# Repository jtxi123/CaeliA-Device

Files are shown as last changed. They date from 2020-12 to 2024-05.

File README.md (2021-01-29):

# CaeliA-Device

## Device using MHZ19 and DHT11 sensors

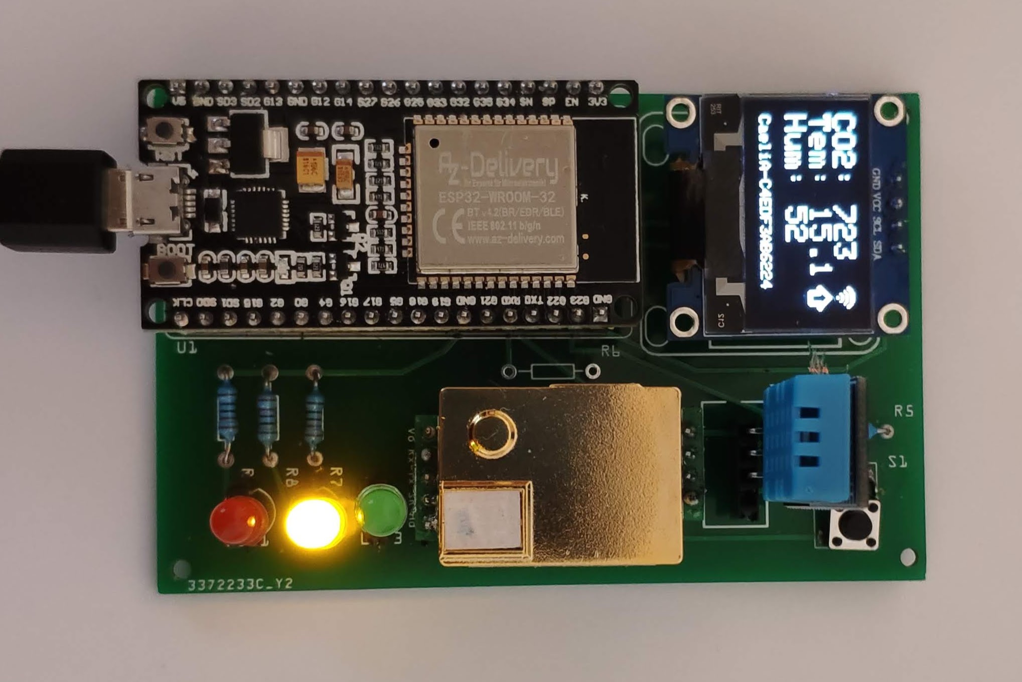
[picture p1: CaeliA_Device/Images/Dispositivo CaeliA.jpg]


## Device using CM1106 and BME280 sensors

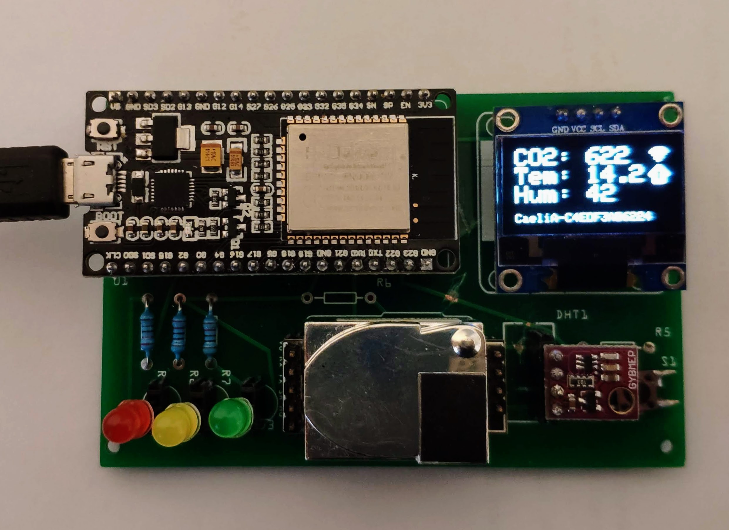
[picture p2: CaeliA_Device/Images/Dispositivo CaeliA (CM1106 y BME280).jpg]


This project describes the design of a CO2 metering for deployment in schools and other public and private places.

The device takes CO2 as well as other environmental readings periodically and publishes them using mqtt to a cloud platform.
The device is equiped with a display and some indicator leds in order to also allow local operation and to signal the warning
CO2 levels.

The device was built using an ESP32 nodemcu and utilizes two sensors:
* MHZ19 or CM1106 CO2 sensor: 
    - An NDIR co2 sensor that supports a serial UART interface.
* DHT11 or BME280 Humidity and Temperature sensor: 
    - The sensor provides temperature and humidity and is interfaced though a PWM
* The software is designed to automatically detect which sensor is present and will use the corresponding sensor for CO2, temperature and humidity.

The device needs a wifi hotspot to connect to Internet and publish the readings.

In order to connect, the device uses the [WifiManager library](https://github.com/tzapu/WiFiManager) to request from the user the connection parameters. 

* On first instalation, the device will start a captive portal AP and request the following:
    - WiFi SSID
    - WiFi password
    - MQTT broker address
    - MQTT broker port
    - MQTT topic
    - URL to check for software updates.
* After parameters are set, the device will connect automatically without user intervention. Parameters are persisted
in the flash SPFFS file system and will be recovered in subsequent reboots.
* The user can force the device to raise the captive portal upon powerup to change any of the existing parameters.

# Calibration

NDIR CO2 sensors must be periodically calibrated to compensate drifts. The device supports three methods:

* Autocalibration (on by default): Whe operating under normal conditions, in operation the device assumes that at some point during a 24h period there will be a base level concentratio (approx. 400ppm) and uses that point to calibrate. 

* Manual calibration: Pressing the multipurpose button while the device is on operation in a base level CO2 concentration will force the device to follow a calibration cycle

* Sending a command from the server (see RPC commands).

The device uses the [fota library](https://github.com/chrisjoyce911/esp32FOTA) library for over the air updates. In will regularly check for firmware updates by checking current firmware version against the version recorded in the sw server.
In the case there is a new version it will download and install it unattended.

# Configuration

When the device stars up it recovers the configuration stored in flash memory and tries to connect. If it succeds i proceeds with the setup and follows to start taking readings from the sensor and publishing them via mqtt. The reading cycle takes place every 20s although it is easy to change.

Onece selected the AP of the arduino board the following screens allo you to configure the different parameters:

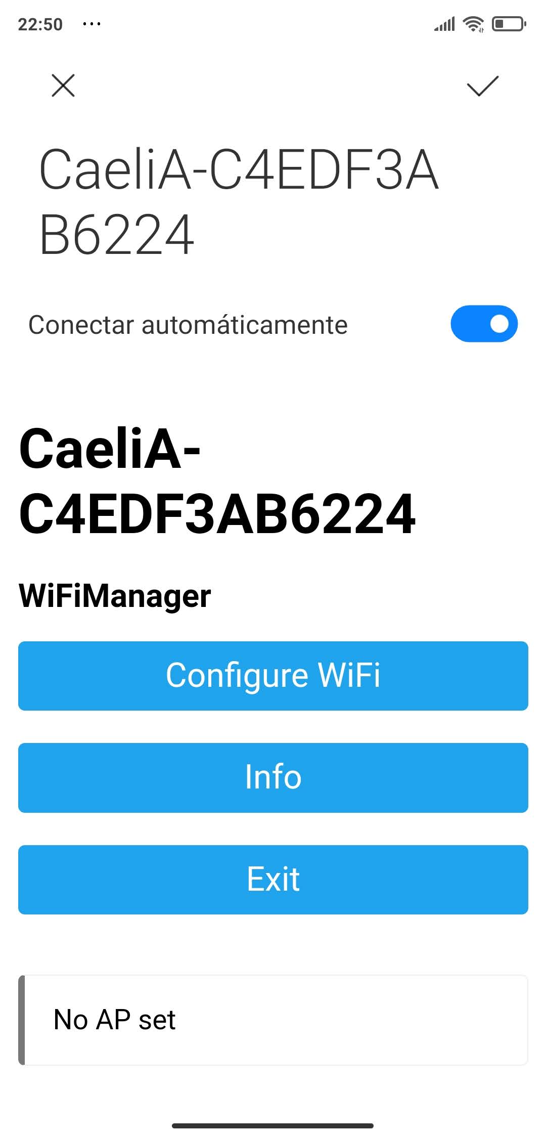
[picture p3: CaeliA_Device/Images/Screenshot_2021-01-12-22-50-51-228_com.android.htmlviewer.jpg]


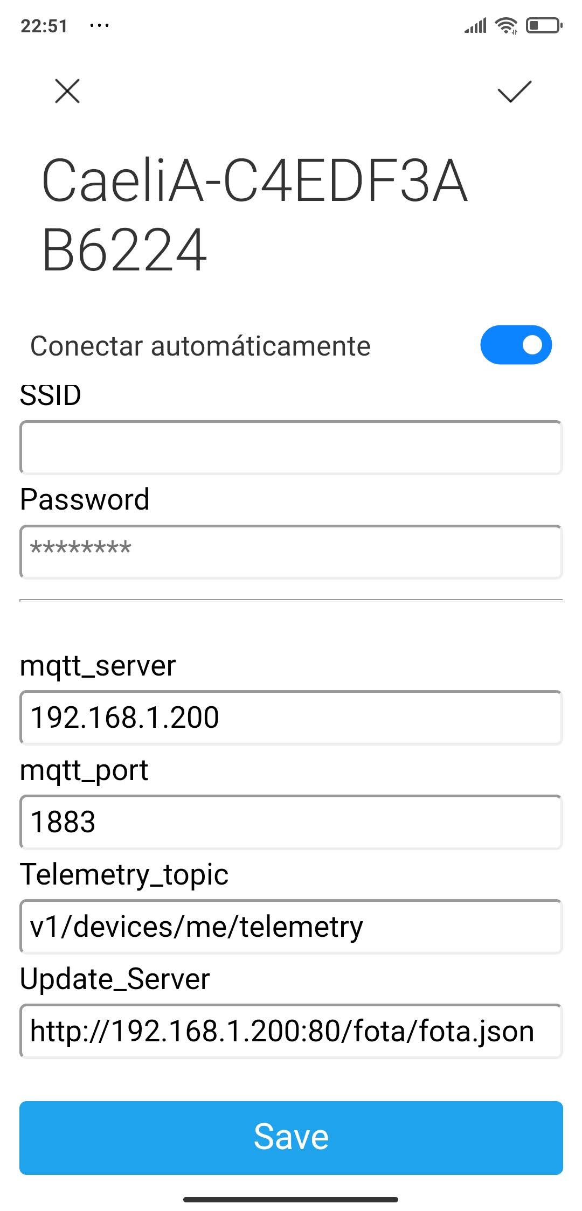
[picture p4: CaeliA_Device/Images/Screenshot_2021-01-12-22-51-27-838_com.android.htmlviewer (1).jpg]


# OTA software update

The device checks periodically a json file stored in a web server, to verify if there is a newer version than the current software loaded on the device. The file also points to the location of the sw which can be stored in a different server. 

```
{
    "type": "CaeliA_esp32_co2",
    "version": 1,
    "host": "192.168.1.200",
    "port": 80, 
    "bin": "/fota/CaeliA_Device.ino.esp32.bin"
}
```

# MQTT Cloud platform

CaeliA device is conceived as a device used to publish into a cloud platform. The cloud platform can also be used to manage the device.

Data on the device can be visualized thoug dashboards such as:

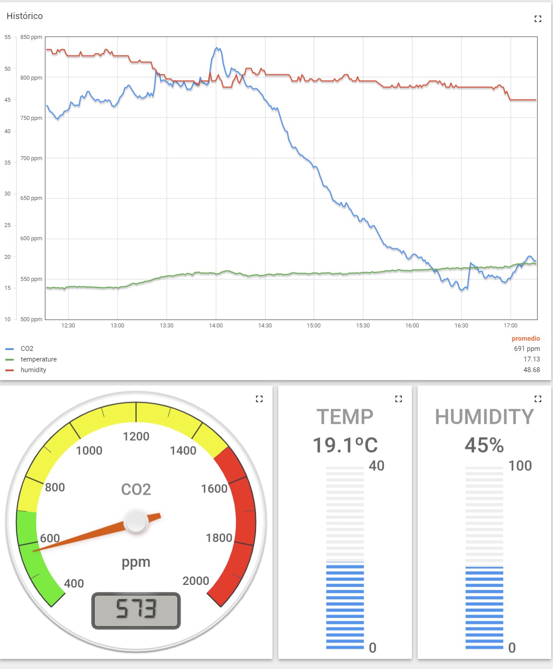
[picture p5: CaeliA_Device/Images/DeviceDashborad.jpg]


The current platform used is ThingsBoard which allows also also to issue RPC commands that the device can interpret. Curtrently the following
RPC calls over MQTT are implemented:

```
setOffset: Add offset to CO2 reading#define DBG_ENABLE_ERROR
calibration: Zero calibration of  device (400 ppm)
autoCalibration: turn autocalibration  on/off
userMessage: Display a message for the user
setLedState: Force LEDs on(2)/off(0)/warning_level(1)
setWarnings: Define warning and danger levels
autoCalibration: turn the autocalibration mode on=true or off=false
version: the device will respond with the uptime and the version number
updateFirmware: the device will load new firmware from the host and filedescriptor parameters
```
 
# Schematics of the device:

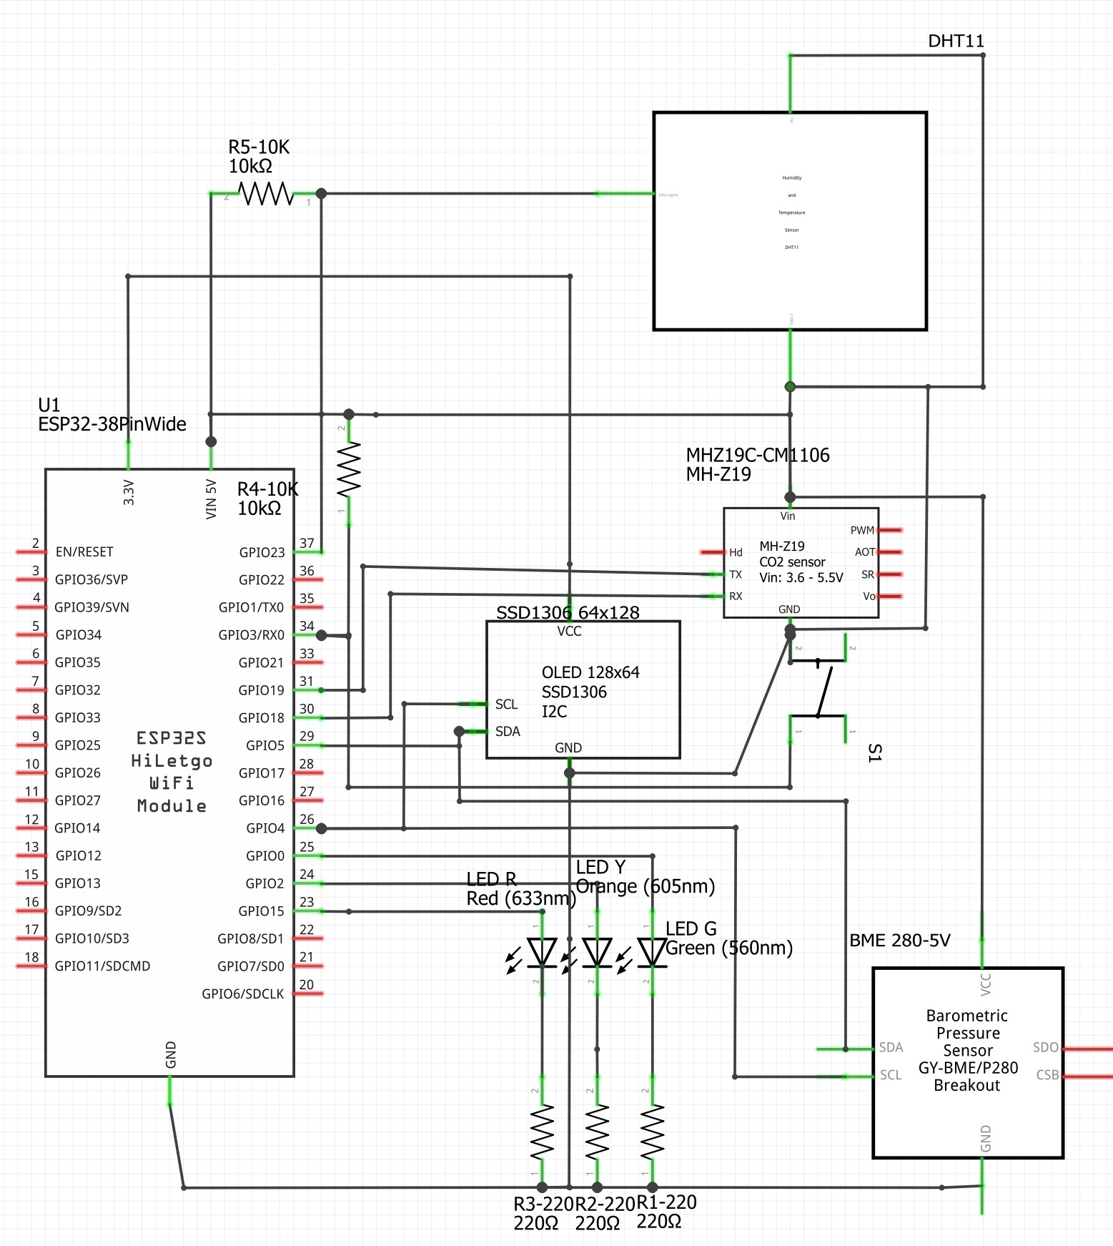
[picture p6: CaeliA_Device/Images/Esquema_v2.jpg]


# and the PCB

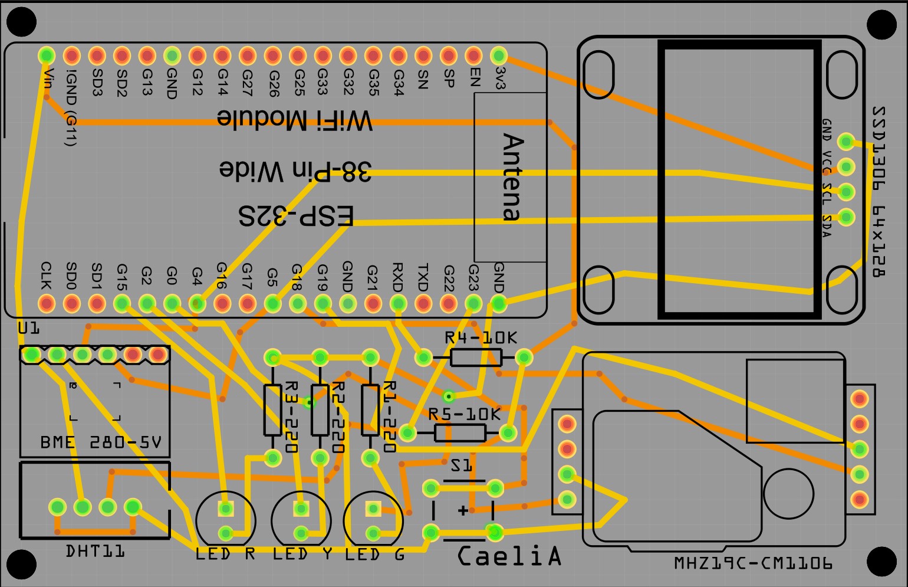
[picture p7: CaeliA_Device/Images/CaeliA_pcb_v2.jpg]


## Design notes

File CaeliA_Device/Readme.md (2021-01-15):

# Note on libraries

## The following libraries have bee used:

* MH-Z19 v 1.5.3 by Jonathan Dempsey:
* WifiManager v2.03 by tzapu
* DHT Sensor Library by Adafruit v1.4.1
* Adafruit SSD1306 Library by Adafruit v2.4.1
* esp32FOTA Library by Chris Joice v 0.1.2
* Thingsboard Library by Thingsboard Team v 0.4.0
* ArduinoHttpClient Library by Arduino v 0.4.0
* Adafruit BME280 Library by Adafruit v 2.1.2
* Arduino 107 debug library by Alexander Entinger
(note:  I had to eliminate the dtostrf.c file from the library since it redefines
the dtostrf which is already defined in the core libraries of the ESP32.)

All libraries can be located through arduino library manager or through the links provided.

## A library was written to support the CM1106
* The library is included

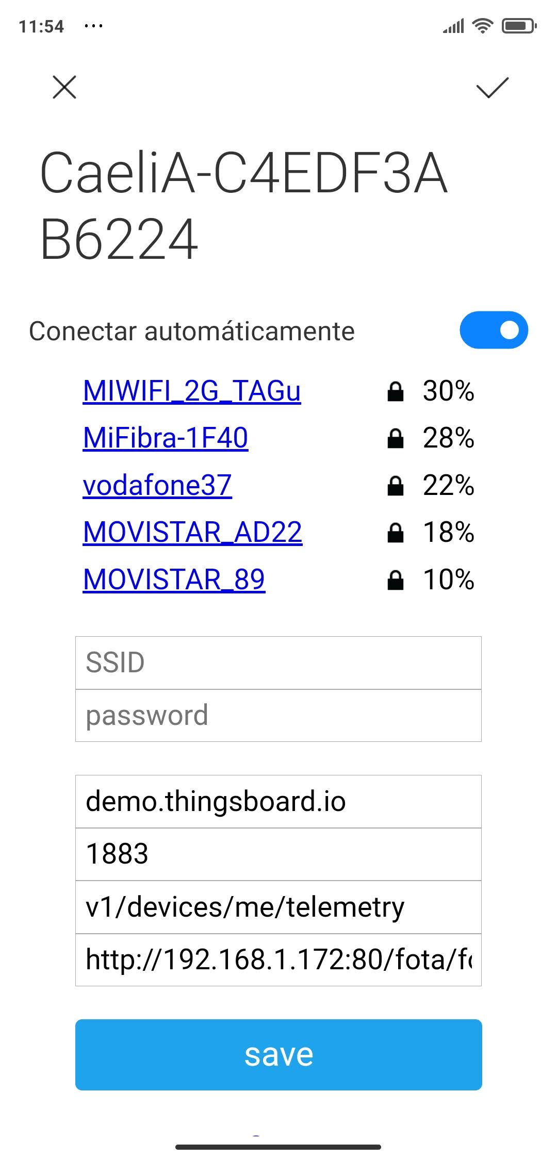
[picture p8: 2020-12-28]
CaeliA_Device/Images/captive_portal.jpg

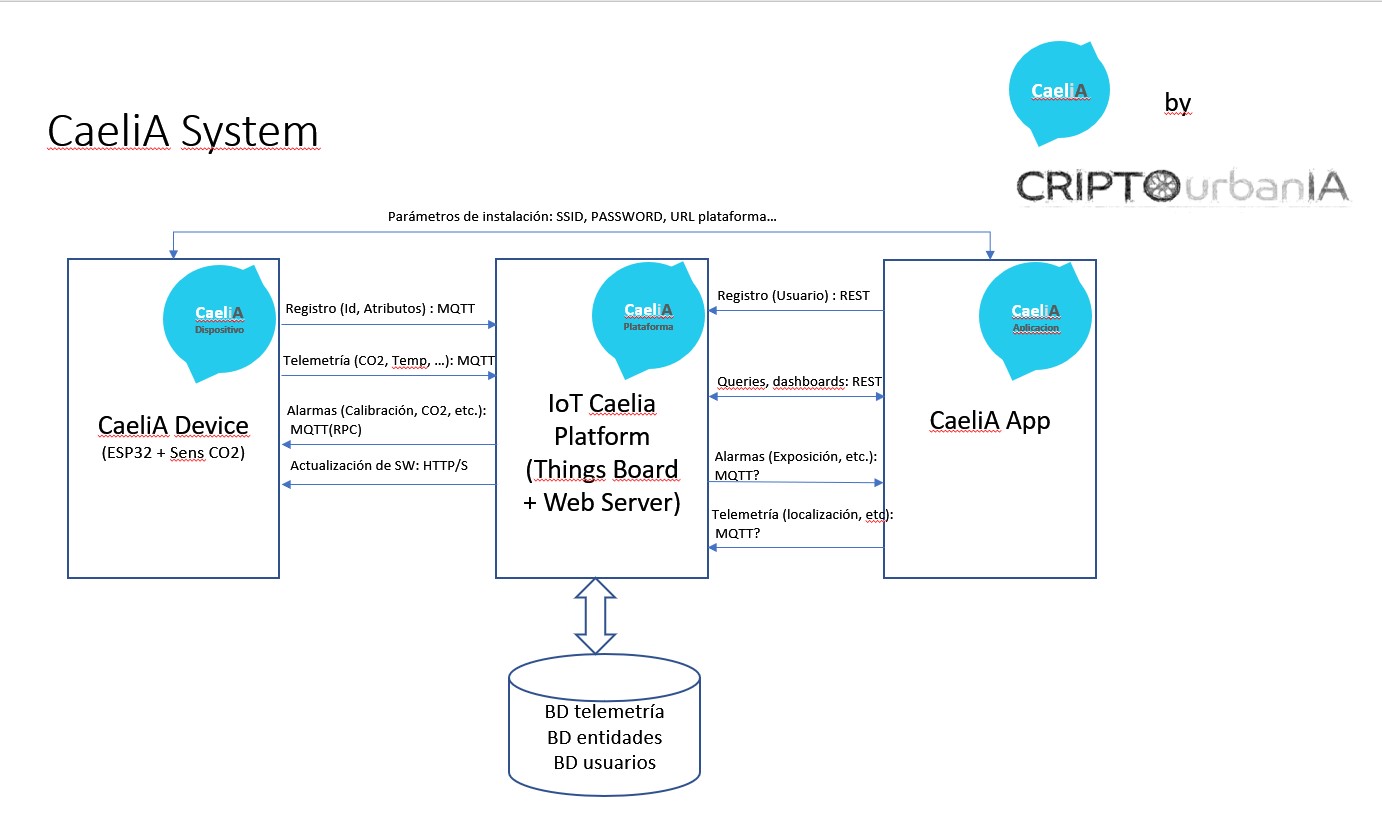
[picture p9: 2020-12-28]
CaeliA_Device/Images/System.jpg

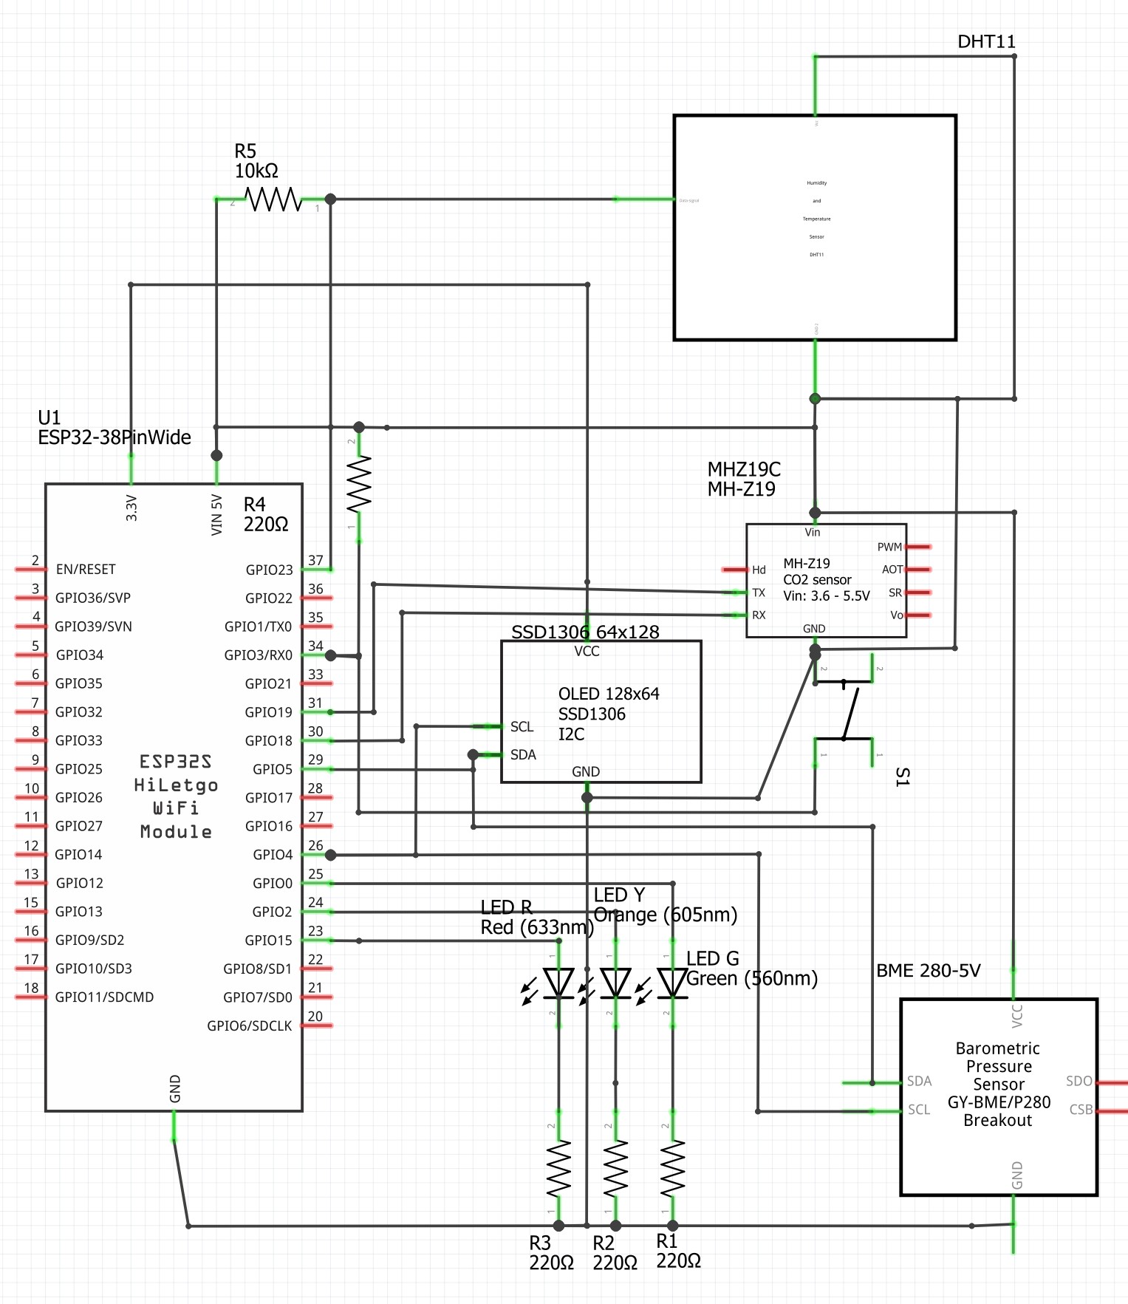
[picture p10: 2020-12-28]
CaeliA_Device/Images/Esquema.jpg

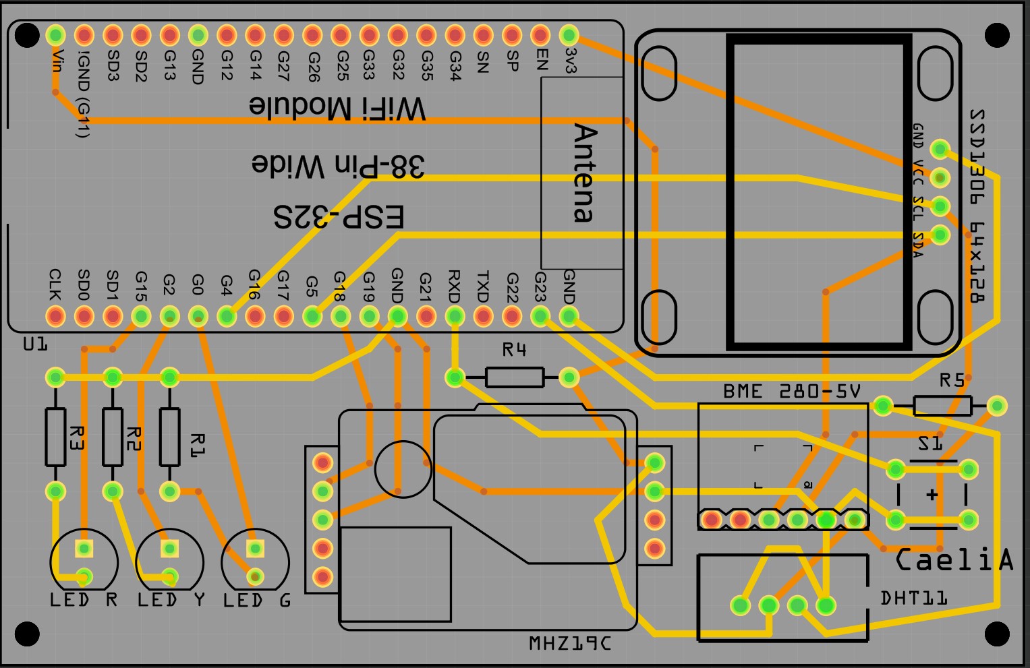
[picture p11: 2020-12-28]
CaeliA_Device/Images/CaeliA_pcb.jpg

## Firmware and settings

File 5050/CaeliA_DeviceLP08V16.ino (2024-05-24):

#define DBG_ENABLE_ERROR
#define DBG_ENABLE_WARNING
#define DBG_ENABLE_INFO
//#define DBG_ENABLE_DEBUG
//#define DBG_ENABLE_VERBOSE
#define RIVAS
#define WIFI_TELEMETRY
//#define LP
#include <107-Arduino-Debug.hpp>
DEBUG_INSTANCE(200, Serial);

#include <WiFi.h>
#include <WiFiClientSecure.h>
#include <HTTPClient.h>
#include <Arduino_MQTT_Client.h>
#include <ThingsBoard.h>  // ThingsBoard SDK
#include <NTPClient.h>
#include <WiFiUdp.h>


// We do theoretically have an Arduino_ESP32_Updater component, which has dependencies on Arduino and used the UpdaterClass,
// but it makes not sense to use that component atleast currently, because it simply implements writing to partitions
// in a very suboptimal way, allocatng 4KB on the heap and even causing undefined behaviour and even memory leaks.
// See https://github.com/espressif/arduino-esp32/issues/7984#issuecomment-1717151822 for more information on the issues with the UpdaterClass.
// Therefore instead it is recommended to use the Epsressif_Updater which directly uses the headers, which are included in the UpdaterClass anyway,
// but because it directly use the OTA Update API see https://docs.espressif.com/projects/esp-idf/en/latest/esp32/api-reference/system/ota.html for more information,
// it is more efficient and does not have any of the aforementioned issues.
// Thanks to those issues it is highly recommended to use the Espressif_Updater as long as the issue has not been resolved on a Arduino level, additional the same is the case
// if an older version of Arduino is used that might not contain the possible fixes yet.
#include <Espressif_Updater.h>



// Whether the given script is using encryption or not,
// generally recommended as it increases security (communication with the server is not in clear text anymore),
// it does come with an overhead tough as having an encrypted session requires a lot of memory,
// which might not be avaialable on lower end devices.
#define ENCRYPTED false

// Firmware title and version used to compare with remote version, to check if an update is needed.
// Title needs to be the same and version needs to be different --> downgrading is possible

const bool check_signature = false;
const bool disable_security = true;
constexpr char CURRENT_FIRMWARE_TITLE[] = "CaeliA_esp32_co2";
constexpr char CURRENT_FIRMWARE_VERSION[] = "1.0.1";
constexpr char FORCEUPDATE[]="9.9.9";


// Maximum amount of retries we attempt to download each firmware chunck over MQTT
//constexpr uint8_t FIRMWARE_FAILURE_RETRIES = 12U;
constexpr uint8_t FIRMWARE_FAILURE_RETRIES = 16U;

// Size of each firmware chunck downloaded over MQTT,
// increased packet size, might increase download speed

constexpr uint16_t FIRMWARE_PACKET_SIZE = 4096U;
//constexpr uint16_t FIRMWARE_PACKET_SIZE = 32768U;


//#define MINID1
#define DEVKIT
#include "esp32-hal-cpu.h"
// File system
#include <FS.h>
#include <SPIFFS.h>

// MQTT port used to communicate with the server, 1883 is the default unencrypted MQTT port,
// whereas 8883 would be the default encrypted SSL MQTT port

#if ENCRYPTED
constexpr uint16_t THINGSBOARD_PORT = 8883U;
// See https://comodosslstore.com/resources/what-is-a-root-ca-certificate-and-how-do-i-download-it/
// on how to get the root certificate of the server we want to communicate with,
// this is needed to establish a secure connection and changes depending on the website.
#include "root_ca.h"
#else
constexpr uint16_t THINGSBOARD_PORT = 1883U;
#endif
constexpr uint32_t MAX_MESSAGE_SIZE = 1024U;


WiFiUDP ntpUDP;
// You can specify the time server pool and the offset (in seconds, can be
// changed later with setTimeOffset() ). Additionaly you can specify the
// update interval (in milliseconds, can be changed using setUpdateInterval() ).
//
//tiempo UTC para tener hora local hy que modificar el
// offset (0) con la función timeClient.setTimeOffset(long timeOffset)
NTPClient timeClient(ntpUDP, "europe.pool.ntp.org", 0, 60000);
//NTPClient timeClient(ntpUDP);

//needed for library for autoconnect
//#include <DNSServer.h>
#include <WebServer.h>
//Debug level for WiFiManager
#define WM_DEBUG_LEVEL 1
#include <WiFiManager.h>

// These values are only relevant for the first run. After that the default values are
// those persisted in the config file.
// If the sw_server is empty the sw will skip updates.
// #define SW_SERVER "raw.githubusercontent.com"
// The json file contains the version available and the pointer to where the bin file is located
// The sw will check the version compare it with the version in the actual sw and update if necessary.
//#define SW_FILE "/jtxi123/CaeliA-Rivas/main/FotaRivas/fota.json"

// This levels can be changed using the RPC call
#define WARN 700;
#define DANGER 1000;

// Variables to store credentials in case we need to reconnect
//char ap_ssid[40];  //to store the wifi ap name
//char ap_pass[40];  //to store the wifi ap password
// directive foor CO2 sensors
// The SW will check which sensor is present. If the definition is commented
// The SW will not check for its presence
#define MHZ19_CO2
#define CM1106_CO2
// If RPC is commented the device will not support RPC
#define RPC
// device has SSD1306 128x64 display
// If DISPLAY is defined the device will check for the presence of a display
// and will use it if present.
#define DISPLAY

#define BAUDRATE 9600  // Device to CO2 sensor Serial baudrate (should not be changed)
#define RX_PIN 19      // Rx pin which the CO2 Sensor Tx pin is attached
#define TX_PIN 18      // Tx pin which the CO2 Sensor Rx pin is attached

#ifdef MHZ19_CO2
#include "MHZ19.h"
#define RANGE_Z19 5000  // Range for MHZ19 CO2 readings
MHZ19 myMHZ19;          // Constructor for library
#endif

#ifdef CM1106_CO2
#include "CM1106.h"  //Using CM1106 Sensor
CM1106 myCM1106;     //Constructor for library
#endif

typedef enum SensorType {
  NOSENSOR = 0,     //No CO2 sensor
  MHZ19sensor = 1,  // MHZ19 sensor
  CM1106sensor = 2  // CM1106 sensor
} SensorType;
SensorType co2Sensor = NOSENSOR;

// Just as with the CO2 sensor both types of temperature and humidity sensors
// can be defined. The SW will check which one is present.
#define DHT  //DHT temperature and hunidity sensor
#ifdef DHT
#include "DHTesp.h"
DHTesp dht;
// Comfort profile
ComfortState cf;
// Pin number for DHT11 data pin
int dhtPin = 23;
int dhtSensor = 0;
#endif
// BME280 temperature, humidity and pressure
#define BME280
#ifdef BME280
#include <Adafruit_Sensor.h>
#include <Adafruit_BME280.h>
#define SEALEVELPRESSURE_HPA (1013.25)
Adafruit_BME280 bme;  // I2C
int bmeSensor = 0;
#endif
#define DEFAULT_TEMP_OFFSET "-3.5"


#ifndef ESP32
#pragma message(THIS EXAMPLE IS FOR ESP32 ONLY !)
#error Select ESP32 board.
#endif
// Wire library to support I2C bus
#include <Wire.h>
#define I2C_SDA 5
#define I2C_SCL 4

#ifdef DISPLAY
#include <Adafruit_SSD1306.h>
// Declaration for an SSD1306 display connected to I2C (SDA, SCL pins)
//#define I2C_SDA 21
//#define I2C_SCL 22
#define SCREEN_WIDTH 128  // OLED display width, in pixels
#define SCREEN_HEIGHT 64  // OLED display height, in pixels
#define OLED_RESET -1     // Reset pin # (or -1 if sharing Arduino reset pin)

//Create the display object
Adafruit_SSD1306 display(SCREEN_WIDTH, SCREEN_HEIGHT, &Wire, OLED_RESET);

//Bitmap Icons for display
#define wifi1_icon16x16_width 16
#define wifi1_icon16x16_height 16
//variable to register the detection of a display at address 0x3C
bool displayPresent = false;  // Variable to annotate if disply was detected
const unsigned char wifi_icon16x2[][2] = {
  0b11111111, 0b11111111,  // ################
  0b00000000, 0b00000000,  //
  0b01111111, 0b11111110,  //  ##############
  0b00000000, 0b00000000,  //
  0b00111111, 0b11111100,  //   ############
  0b00000000, 0b00000000,  //
  0b00011111, 0b11111000,  //    ##########
  0b00000000, 0b00000000,  //
  0b00001111, 0b11110000,  //     ########
  0b00000000, 0b00000000,  //
  0b00000111, 0b11100000,  //      ######
  0b00000000, 0b00000000,  //
  0b00000011, 0b11000000,  //       ####
  0b00000000, 0b00000000,  //
  0b00000001, 0b10000000,  //        ##
  0b00000000, 0b00000000,  //
};

#define arrow_up_icon16x16_width 16
#define arrow_up_icon16x16_height 16
const unsigned char arrow_up_icon16x16[] = {
  0b00000001, 0b10000000,  //        ##
  0b00000011, 0b11000000,  //       ####
  0b00000111, 0b11100000,  //      ######
  0b00001111, 0b11110000,  //     ########
  0b00011110, 0b01111000,  //    ####  ####
  0b00111100, 0b00111100,  //   ####    ####
  0b01111000, 0b00011110,  //  ####      ####
  0b11111100, 0b00111111,  // ######    ######
  0b11111100, 0b00111111,  // ######    ######
  0b01111100, 0b00111110,  //  #####    #####
  0b00011100, 0b00111000,  //    ###    ###
  0b00011100, 0b00111000,  //    ###    ###
  0b00011100, 0b00111000,  //    ###    ###
  0b00011111, 0b11111000,  //    ##########
  0b00011111, 0b11111000,  //    ##########
  0b00001111, 0b11110000,  //     ########
};

#define cancel_icon16x16_width 16
#define cancel_icon16x16_height 16
const unsigned char cancel_icon16x16[] = {
  0b00000000, 0b00000000,  //
  0b00000000, 0b00000000,  //
  0b00111000, 0b00001110,  //   ###       ###
  0b00111100, 0b00011110,  //   ####     ####
  0b00111110, 0b00111110,  //   #####   #####
  0b00011111, 0b01111100,  //    ##### #####
  0b00001111, 0b11111000,  //     #########
  0b00000111, 0b11110000,  //      #######
  0b00000011, 0b11100000,  //       #####
  0b00000111, 0b11110000,  //      #######
  0b00001111, 0b11111000,  //     #########
  0b00011111, 0b01111100,  //    ##### #####
  0b00111110, 0b00111110,  //   #####   #####
  0b00111100, 0b00011110,  //   ####     ####
  0b00111000, 0b00001110,  //   ###       ###
  0b00000000, 0b00000000,  //
};
#endif



// Helper macro to calculate array size
#define COUNT_OF(x) ((sizeof(x) / sizeof(0 [x])) / ((size_t)(!(sizeof(x) % sizeof(0 [x])))))

char TOKEN[40] = "CaeliA-28092EA8CC84";
char WIFI_SSID[40] = "MIWIFI_2G_Zbiz";
char WIFI_PASSWORD[40] = "ZGHhi9qh";
// ThingsBoard server instance.
//#define THINGSBOARD_SERVER "thingsboard.cloud"
#define THINGSBOARD_SERVER "demo.thingsboard.io"
//#define THINGSBOARD_SERVER  "192.168.1.100"
#define TELEMETRY_TOPIC "v1/devices/me/telemetry"

// Baud rate for debug serial console
#define SERIAL_DEBUG_BAUD 115200

#define MAX_KEYS 20      //Maximum number of Telemetry key-value pairs
#define NO_KEY ""        //empty key tag name
#define DISPLAY_LINES 8  //Number of lines on display


// Create the ThingsBoard client
#if ENCRYPTED
WiFiClientSecure espClient;
#else
WiFiClient espClient;
#endif
// Initialize ThingsBoard instance
Arduino_MQTT_Client mqttClient(espClient);

ThingsBoard tb(mqttClient, MAX_MESSAGE_SIZE);

//ThingsBoardSized tb(mqttClient, MAX_MESSAGE_SIZE);
//ThingsBoard tb(espClient, MAX_MESSAGE_SIZE);
// Initalize the Updater client instance used to flash binary to flash memory

Espressif_Updater updater;

// Statuses for updating
bool currentFWSent = false;
bool updateRequestSent = false;
bool updating = false;
bool forceupdateflag = false;


// the Wifi radio's status
int wifiStatus = WL_IDLE_STATUS;

DynamicJsonDocument configJson(1024);  //json document to store config parameters

//Temperature Offset
float Toffset = 0;

//Pins to control the LEDs
#ifdef MINID1
#define RED 17
#define YELLOW 21
#define GREEN 25
#else
#define RED 15
#define YELLOW 2
#define GREEN 0
#endif

// Array with LEDs that should be controlled from ThingsBoard
uint8_t leds_control[] = { RED, YELLOW, GREEN };

#ifdef MINID1
#define PIN_CONFIGURE 25  //Pin used to force configuration at boot
#else
#define PIN_CONFIGURE 3  //Pin used to force configuration at boot
#endif

#define PIN_BOOT 0
// global timeStamp variables
unsigned long current_time;
unsigned long last_time;
unsigned long display_time;
unsigned long start_time;  //record the initial millis() to wait for sensor stabilization
unsigned long bootTimeStamp;

struct CONNECTION {
  bool wifi = false;
  int wifiStrength = 0;
  bool mqtt = false;
  bool rpc = false;
} connStatus;


#ifdef RPC
// Set to true if application is subscribed for the RPC messages.
bool subscribed = false;

// Watchdog if the system is a long time with no connection it will reboot
#define TWD 3600  // 1 hour
//#define TWD 1000 // 1000 sec
//#define TWD 0 // Disable watchdog
const unsigned long wdtTimeout = 1000 * TWD;  //time in ms to trigger the watchdog
hw_timer_t *timer = NULL;
// In the case of watchdog interrupt, this function is called
void IRAM_ATTR resetModule() {
  ets_printf("reboot\n");  // When called it reboots
  esp_restart();
}
// Take measurements of the Wi-Fi strength and return the average result.
//int fake = 0;
int getStrength(bool raw = false) {
  int rssi = 0;
  int strength = 0;
  rssi = WiFi.RSSI();
  if (!raw) {
    if (rssi > -55) strength = 7;
    else if (rssi > -59) strength = 6;
    else if (rssi > -63) strength = 5;
    else if (rssi > -67) strength = 4;
    else if (rssi > -71) strength = 3;
    else if (rssi > -75) strength = 2;
    else if (rssi > -79) strength = 1;
    //strength = fake++ % 8;
    DBG_INFO("WiFi level: %i", strength);
  } else strength = rssi;
  return strength;
}



// Processes functions for RPC calls
// RPC_Data is a JSON variant, that can be queried using operator[]
// See https://arduinojson.org/v5/api/jsonvariant/subscript/ for more details
// Function to modify offset to adjust co2 measurments.
int co2Offset = 0;
static StaticJsonDocument<JSON_OBJECT_SIZE(1)> docresponse;
static RPC_Response processSetOffset(const RPC_Data &data) {
  // Process data
  docresponse.clear();
  co2Offset += int(data);  //Change co2 offset

  DBG_INFO("Received the set offset RPC method");
  DBG_INFO("Set new CO2_offset: %i", co2Offset);
  docresponse["co2Offset"] = co2Offset;
  //return RPC_Response(NULL, co2Offset);
  return RPC_Response(docresponse);
}

// Function to turn on or off auto calibration.
static RPC_Response processAutoCalibration(const RPC_Data &data) {
  docresponse.clear();
  DBG_INFO("Set auto calibration");
  configJson["auto_calibration"] = bool(data);
  saveConfigFile(configJson);
#ifdef MHZ19_CO2
  if (co2Sensor == MHZ19sensor) {

    myMHZ19.autoCalibration(bool(configJson["auto_calibration"]));
    // set Range to RANGE_Z19 using a function, see below (disabled as part of calibration)
    myMHZ19.setRange(RANGE_Z19);
  }
#endif
#ifdef CM1106_CO2
  if (co2Sensor == CM1106sensor) {
    myCM1106.autoCalibration(bool(configJson["auto_calibration"]), 7);
  }
#endif
  docresponse["AutoCalibration"] = bool(configJson["auto_calibration"]);
  return RPC_Response(docresponse);
  //return RPC_Response("AutoCalibration", bool(configJson["auto_calibration"]));
}
// This flag will be raised if calibration is requested.
// it will be reset after calibration
bool calibrationFlag;
static RPC_Response processCalibration(const RPC_Data &data) {
  calibrationFlag = true;
  docresponse.clear();
  DBG_INFO("Received the calibration RPC command");
  DBG_INFO("Set the calibration flag: %i", calibrationFlag);
  docresponse["calibration"] = calibrationFlag;
  return RPC_Response(docresponse);
  //return RPC_Response("calibration", calibrationFlag);
}

// Function to receive a message with a severity level.
String userMessage = "";
int messageLevel = 0;
static RPC_Response processUserMessage(const RPC_Data &data) {
  const char *message;

  DBG_INFO("Received the get userMessage method");

  message = data["message"];
  userMessage = String(message);
  messageLevel = data["level"];

  DBG_INFO("Mensaje: %s Nivel: %i", message, messageLevel);
  docresponse["message"] = message;
  return RPC_Response(docresponse);
  //return RPC_Response("message", message);
}

// Function to control leds
// when led_state ==1 led will light in accordance with the CO2 level
// when led_state ==2 led is always on
// when led_state ==0 the led is always off

int led_state[3] = { 1, 1, 1 };

static RPC_Response processSetLedState(const RPC_Data &data) {
  docresponse.clear();
  Serial.println("Received the set setLedState RPC method");
  serializeJson(data, Serial);
  int led = data["led"];
  int enabled = data["enabled"];

  if (led < COUNT_OF(leds_control)) {

    DBG_INFO("Setting LED %i  (GPIO%i) to state %i", led, leds_control[led], enabled);
    led_state[led] = enabled;
    if (enabled == 2) digitalWrite(leds_control[led], 1);
    if (enabled == 0) digitalWrite(leds_control[led], 0);
  }
  //return RPC_Response(data["led"], enabled);
  docresponse["enabled"] = enabled;
  return RPC_Response(docresponse); 
  //return RPC_Response("enabled", enabled);
}

int level_warn = WARN;
int level_danger = DANGER;

static RPC_Response processSetWarnings(const RPC_Data &data) {
  docresponse.clear();
  Serial.println("Received the set setWarnings RPC method");

  level_warn = data["warning"];
  level_danger = data["danger"];

  DBG_INFO("Setting Warning levels");
  DBG_INFO("From 0 to %i ppm good", level_warn);
  DBG_INFO("From %i to %i ppm fair", level_warn + 1, level_danger);
  DBG_INFO("Above %i  ppm danger", level_danger);

  docresponse["warning"] = level_warn;
  return RPC_Response(docresponse); 
  //return RPC_Response("warning", level_warn);
}
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
void loop() {
  delay(100);
  unsigned long current_time = millis();
  
  if (current_time - last_time > MEAS_PERIOD * 1000) {
    measTask();
    DBG_VERBOSE("Enable sleep : %s", (WiFi.getSleep()) ? "True" : "False");
    //WiFi.setSleep(true);
    last_time = current_time;
  }
#ifdef LP
  if (current_time - display_time > WAKE_PERIOD * 1000) {
    displayState = false;
    display.ssd1306_command(SSD1306_DISPLAYOFF);
  }
#endif
  // Check if user presses the configure button in order to calibrate the device

  if (!digitalRead(PIN_CONFIGURE)) {
    display.ssd1306_command(SSD1306_DISPLAYON);
    displayState = true;
    //trigger calibration if button is pressed for more than 5 secs
    if (pressed) {
      if (current_time - display_time > 5000) calibrationFlag = true;
    } else {
      DBG_INFO("Config PIN pressed");
      display_time = current_time;
    }
    pressed = true;
  } else pressed = false;
  
  if (!tb.connected()) {
    // Reconnect to the ThingsBoard server,
    // if a connection was disrupted or has not yet been established
    DBG_INFO("Connecting to: (%s) with token (%s)\n", THINGSBOARD_SERVER, TOKEN);
    if (!tb.connect(THINGSBOARD_SERVER, TOKEN, THINGSBOARD_PORT)) {
      DBG_INFO("Failed to connect");
      return;
    }
  }
  if (!updating) {
    updateFW();
    //tb.Firmware_Send_State(FW_STATE_UPDATED);
  } 
  tb.loop();
}

unsigned long last_m = 0;
#define UPDATE_PERIOD 60 //seconds
void updateFW()
{
  unsigned long current_m;
  current_m = millis();
  if (last_m == 0) last_m = current_m-UPDATE_PERIOD*1000-1; //first execution
  if (((current_m - last_m) > UPDATE_PERIOD*1000))
  {
    updateRequestSent = false;
    if (forceupdateflag) {
      currentFWSent = false;
      DBG_INFO("Version: %s", FORCEUPDATE);
      /*
      if (!currentFWSent) {
        currentFWSent = tb.Firmware_Send_Info(CURRENT_FIRMWARE_TITLE, FORCEUPDATE) && tb.Firmware_Send_State(FW_STATE_UPDATED);
        DBG_INFO("Update info");
      }
      */
      if (!updateRequestSent) {
        DBG_INFO("Firwmare Update...");
        static const OTA_Update_Callback forcecallback(&progressCallback, &updatedCallback, CURRENT_FIRMWARE_TITLE,
                    FORCEUPDATE, &updater, FIRMWARE_FAILURE_RETRIES, FIRMWARE_PACKET_SIZE);
      // See https://thingsboard.io/docs/user-guide/ota-updates/
        // to understand how to create a new OTA pacakge and assign it to a device so it can download it.
        updateRequestSent = tb.Start_Firmware_Update(forcecallback);
      }

    } else{
      DBG_INFO("Version: %s", CURRENT_FIRMWARE_VERSION);
      /*
      if (!currentFWSent) {
        // Firmware state send at the start of the firmware, to inform the cloud about the current firmware and that it was installed correctly,
        // especially important when using OTA update, because the OTA update sends the last firmware state as UPDATING, meaning the device is restarting
        // if the device restarted correctly and has the new given firmware title and version it should then send thoose to the cloud with the state UPDATED,
        // to inform any end user that the device has successfully restarted and does actually contain the version it was flashed too
        tb.Firmware_Send_State(FW_STATE_UPDATED);
        currentFWSent = tb.Firmware_Send_Info(CURRENT_FIRMWARE_TITLE, CURRENT_FIRMWARE_VERSION);
        DBG_INFO("Update info");
      }
      */
      if (!updateRequestSent) {
        DBG_INFO("Firwmare Update...");
        static const OTA_Update_Callback fwcallback(&progressCallback, &updatedCallback, CURRENT_FIRMWARE_TITLE,
                    CURRENT_FIRMWARE_VERSION, &updater, FIRMWARE_FAILURE_RETRIES, FIRMWARE_PACKET_SIZE);
        // See https://thingsboard.io/docs/user-guide/ota-updates/
        // to understand how to create a new OTA pacakge and assign it to a device so it can download it.
        updateRequestSent = tb.Start_Firmware_Update(fwcallback);
        // delay(1000);
        // tb.Firmware_Send_State(FW_STATE_UPDATED);
      }

    }
    last_m = current_m;
  }
}

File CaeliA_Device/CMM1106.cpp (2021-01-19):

/* -------------------------------------------------
  Author: Juan Goicolea juan.goicolea@gmail.com

  Version: 1.5.1

  License: LGPLv3

  Library supporting CM1106 sensors
  ----------------------------------------------------- */

#include "CM1106.h"
//#define CM1106_ERRORS
//#define DEBUGLIB

void printHex(uint8_t num) {
  char hexCar[3];

  sprintf(hexCar, "%02X", num);
  hexCar[3] = '\0';
  Serial.print(hexCar);
}


/*#########################-Commands-##############################*/

byte CM_Commands[6] = {
  0x01, // 0 Read measured result of CO2
  0x10, // 1 Open/ Close ABC and set ABC parameter
  0x03, // 2 Calibrate concentration value of CO2
  0x1F, // 3 Read the serial number of the sensor
  0x1E, // 4 Read software version
  0x10, // 5 ABC close
};
int CM_rlenr[6] = {
  8, // 0 Read measured result of CO2
  4, // 1 Open/ Close ABC and set ABC parameter
  4, // 2 Calibrate concentration value of CO2
  9, // 3 Read the serial number of the sensor
  15, // 4 Read software version
  4, // 5 ABC close
};
int CM_rlens[6] = {
  4, // 0 Read measured result of CO2
  10, // 1 Open/ Close ABC and set ABC parameter
  6, // 2 Calibrate concentration value of CO2
  4, // 3 Read the serial number of the sensor
  4, // 4 Read software version
  10, // 5 ABC close
};
/*#####################-Initiation Functions-#####################*/

void CM1106::begin(Stream &serial)
{
  // establish connection
  mySerial = &serial;
}


/*########################-Get Functions-##########################*/

int CM1106::getCO2(bool isunLimited, bool force)
{
  unsigned int validRead = 0;
  provisioning(GETCO2);

  if (this->errorCode == CM_RESULT_OK )
  {
    validRead = makeInt(this->storage.responses.GETCO2[3], this->storage.responses.GETCO2[4]);
  }
  return validRead;
}

byte CM1106::getStatus()
{
  return this->storage.responses.GETCO2[5];
}

void CM1106::getSerialN(byte* rSerialN)
{
  provisioning(GETSN);
  if (this->errorCode == CM_RESULT_CRC) this->errorCode = CM_RESULT_OK; //bug in firmware
  if (this->errorCode == CM_RESULT_OK)
  {
    memcpy(rSerialN, this->storage.responses.STAT + 3, 5);
  }
  else
  {
    memset(rSerialN, 0, 5);
  }
}


void CM1106::getVersion(char rVersion[])
{
  provisioning(GETFIRMWARE);

  if (this->errorCode == CM_RESULT_OK)
    for (byte i = 0; i < 10; i++)
    {
      rVersion[i] = char(this->storage.responses.STAT[i + 3]);
    }

  else
    memset(rVersion, 0, 10);
}



byte* CM1106::getLastResponse()
{
  //provisioning(GETCO2);

  if (this->errorCode == CM_RESULT_OK)
    return (this->storage.responses.GETCO2);

  else
    return 0;
}


void CM1106::autoCalibration(bool isON, byte ABCPeriod)
{
  if (isON) provisioning(ABC, ABCPeriod);
  else provisioning(ABC_off, ABCPeriod);
}

void CM1106::calibrate(int rangeCal)
{
  if (rangeCal)
  {

    provisioning(ZEROCAL, rangeCal);
  }

  else
    provisioning(ZEROCAL, 400);
}

/*######################-Utility Functions-########################*/

void CM1106::printCommunication(bool isDec, bool isPrintComm)
{
  this->storage.settings._isDec = isDec;
  this->storage.settings.printcomm = isPrintComm;
}

/*######################-Inernal Functions-########################*/

void CM1106::provisioning(Command_Type commandtype, int inData)
{
  /* construct command */
#ifdef DEBUGLIB
  Serial.println("provisioning...");
  Serial.println("commandtype: " + String(commandtype) + " inData: " + String(inData));
#endif
  constructCommand(commandtype, inData);
#ifdef DEBUGLIB
  byte* buffer = this->storage.constructedCommand;
  Serial.print("Command to be sent: ");
  for (int i = 0; i < CM_rlens[commandtype]; i++)
  {
    printHex(buffer[i]);
    Serial.print(" ");
  }
  Serial.println();
#endif
  /* write to serial */

  write(this->storage.constructedCommand, CM_rlens[commandtype]);

  /*return response */
  handleResponse(commandtype);

}

void CM1106::constructCommand(Command_Type commandtype, int inData)
{
  /* values for conversions */
  byte High;
  byte Low;

  /* Temporary holder */
  byte asemblecommand[CM1106_DATA_LEN];
#ifdef DEBUGLIB
  Serial.println("constructCommand");
  Serial.println("commandtype: " + String(commandtype) + " inData: " + String(inData));
#endif

  /* prepare arrays */
  memset(asemblecommand, 0, CM_rlens[commandtype]);
  memset(this->storage.constructedCommand, 0, CM_rlens[commandtype]);

  /* set start byte' */
  asemblecommand[0] = 0x11; //Start byte

  /* set  length of payload */
  asemblecommand[1] = 1; //Length of frame bytes= data length +1 (including CMD+DATA)

  /* set command */
  asemblecommand[2] = CM_Commands[commandtype]; // assign command value

  switch (commandtype)
  {
    case ABC:
      if (this->storage.settings.ABCRepeat == false)
      {
        asemblecommand[1] = 7;
        asemblecommand[3] = 0x64;
        asemblecommand[4] = 0x0; //0x2 to close
        asemblecommand[5] = inData; //Calibration cycle
        asemblecommand[6] = 400 / 256; //Calibration value
        asemblecommand[7] = 400 % 256;
        asemblecommand[8] = 0x64;
      }
      break;

    case ABC_off:
      if (this->storage.settings.ABCRepeat == false)
      {
        asemblecommand[1] = 7;
        asemblecommand[3] = 0x64;
        asemblecommand[4] = 0x02; //0x2 to close
        asemblecommand[5] = inData; //Calibration cycle
        asemblecommand[6] = 400 / 256; //Calibration value
        asemblecommand[7] = 400 % 256;
        asemblecommand[8] = 0x64;
      }
      break;

    case GETCO2:
      break;

    case ZEROCAL:
      if (inData)
      {
        asemblecommand[1] = 3;
        asemblecommand[3] = inData / 256; //Calibration value
        asemblecommand[4] = inData % 256;
      }
      break;

    case GETSN:
      break;

    case GETFIRMWARE:
      break;

    case GETLASTRESP:
      break;
  }


  /* set checksum */
  byte len = asemblecommand[1] + 2;
  asemblecommand[CM_rlens[commandtype] - 1] = getCRC(asemblecommand, CM_rlens[commandtype] - 1);
  //asemblecommand[CM_rlens[commandtype]-1] = getCRC(asemblecommand, len);

#ifdef DEBUGLIB
  Serial.println("Len: " + String(asemblecommand[1]));
  printHex(asemblecommand[1]);
  Serial.println();
  Serial.print("Assembled command: ");
  for (int i = 0; i < CM_rlens[commandtype]; i++)
  {
    printHex(asemblecommand[i]);
    Serial.print(" ");
  }
  Serial.println();
#endif

  /* copy bytes from asemblecommand to constructedCommand */
  memcpy(this->storage.constructedCommand, asemblecommand, CM_rlens[commandtype]);
}

void CM1106::write(byte toSend[], int wlen)
{
  /* for print communications */
  if (this->storage.settings.printcomm == true)
    printstream(toSend, true, this->errorCode);

  /* transfer to buffer */
  mySerial->write(toSend, wlen);

  /* send */
  mySerial->flush();
}
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

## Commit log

2021-01-05 Update CaeliA_Device.ino
    Added support for the CM1106 CO2 sensor (untested you must uncomment the #define CM1106_CO2 line and comment the #define MHZ19_CO2
    Changed some code in the calibration sections
    Changed version of the WiFiManager Library
    Other small improvements and refactoring
2021-01-07 Add files via upload
    Debugged support for CM1106. The device will now detect which sensor is plugged and will use the appropriate library calls. Also debug printing has been changed to use the 107 Arduino debug library.
2021-01-09 Add files via upload
    Code cleanup.
    Autodetection of the CO2 sensor, the display and the temperature and humidity sensors.
2021-01-19 change name of calibrate function
